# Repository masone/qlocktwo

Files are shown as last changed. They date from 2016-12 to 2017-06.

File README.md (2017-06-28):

# qlocktwo

Arduino based DIY qlocktwo clone. French. Original: http://qlocktwo.com

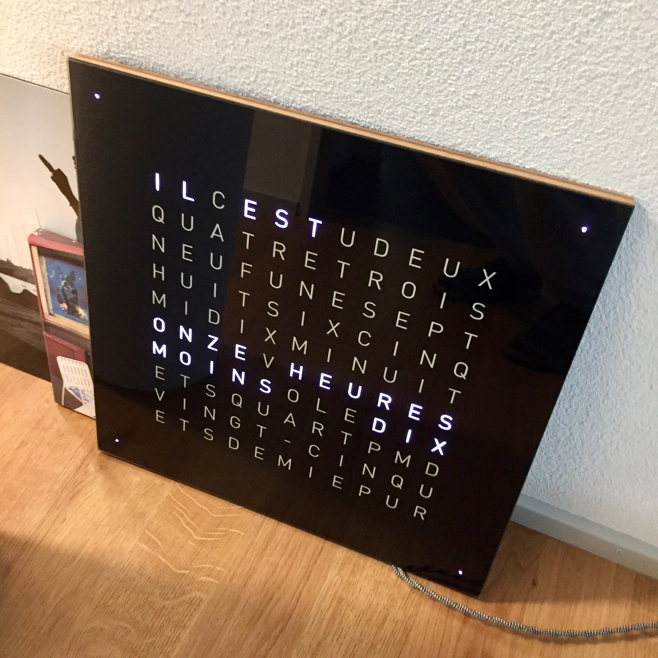
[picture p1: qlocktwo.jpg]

         
## Inspiration

* https://www.flickr.com/photos/ruudburger/sets/72157622708125775/           
* https://www.flickr.com/photos/eokgnah/sets/72157626846176659
* http://jamesbastow.com/wiki/Antelope
* http://imgur.com/a/iMXmj?gallery
* http://www.highonsolder.com/blog/2011/1/8/arduino-word-clock.html

## Resources
                  
* RTC wiring example: http://www.hobbyist.co.nz/?q=real_time_clock
* RTC code examples: https://learn.adafruit.com/ds1307-real-time-clock-breakout-board-kit/understanding-the-code
* 8806 led strip overview: http://www.adafruit.com/product/306
* 8806 led strip code examples: https://learn.adafruit.com/adafruit-neopixel-uberguide/arduino-library
* Wire library (i2c): http://playground.arduino.cc/Main/WireLibraryDetailedReference
* Font: Din regular, 59$: http://www.fonts.com/font/fontfont/ff-din/regular
* Handling vinyl foils, weeding, transfer tape, etc: https://www.youtube.com/watch?v=9TwPV1Wdoog
* Oracal 631-070: http://www.orafol.com/gp/americas/en/products/search-result-gpam-product-details/items/oracal-631-exhibition-cal
* Oratape HT55: http://www.orafol.com/gp/americas/en/products/sign-display-tapes-9755-product-details/items/oratape-ht55-decorative-film-application-tape

## Material

* Vinyl sticker: 456x456mm, black matt, Reverse Cut from https://www.vinylletteringonline.co.uk
* Magnets: MM-S15-3N, 15x3mm, NiCuNi, 2.9kg from https://www.supermagnete.ch
* Wood and glass: 456x456mm from http://jumbo.ch

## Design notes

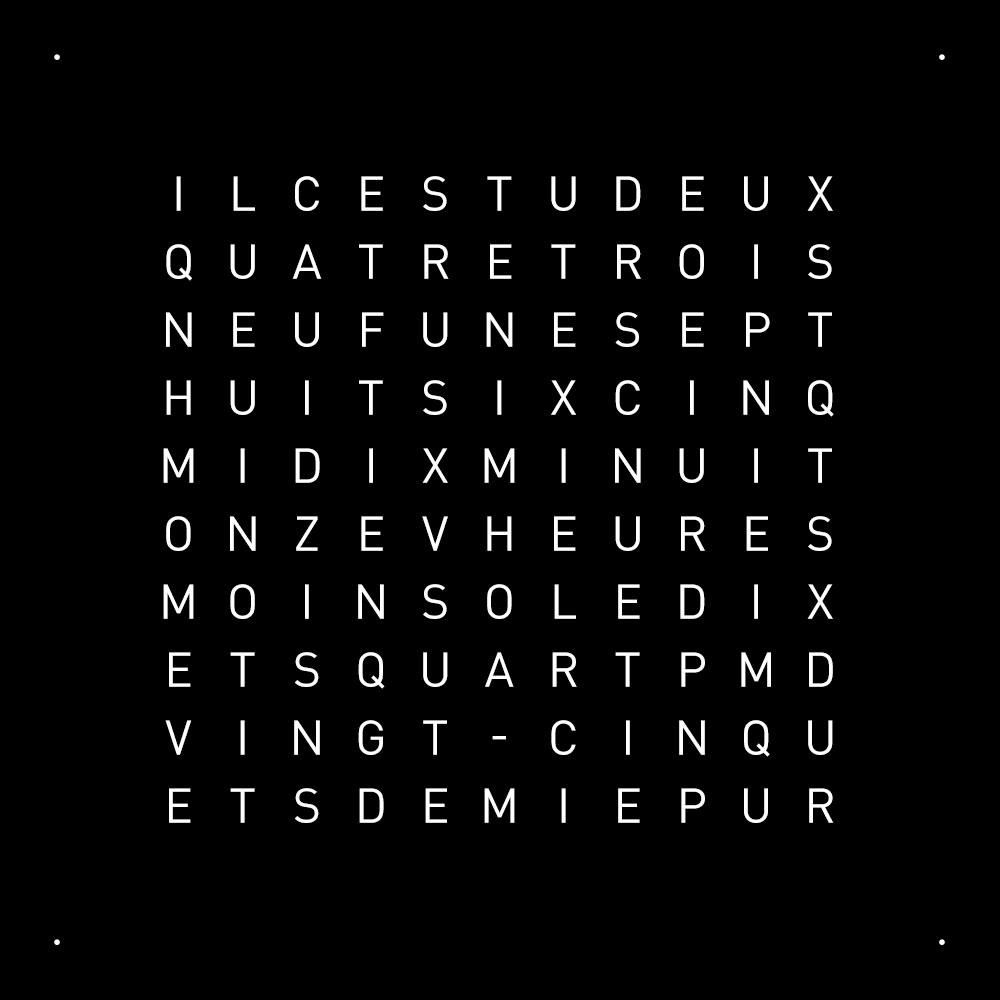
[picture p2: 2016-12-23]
front.jpg

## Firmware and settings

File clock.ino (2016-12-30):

#include "Wire.h"
#include "math.h"
#include "RTClib.h"
#include "LPD8806.h"
#include "SPI.h" // lpd8806 dependency

// RTC SCL (yellow): Analog in 5
// RTC SDA (blue): Analog in 4

int ledDataPin  = 6; // LED DI (blue), digital
int ledClockPin = 7; // LED CI (yellow), digital
int lightPin = 1; // Photoresistor, Analog
int buttonPin = 4; // Push button, digital

DateTime now;
int intensity = 100;
int min_intensity = 10;
int max_intensity = intensity;
int nLEDs = 118;
int reset = 1;

RTC_DS1307 rtc;
LPD8806 leds = LPD8806(nLEDs, ledDataPin, ledClockPin);

void (*words_hour[24])();
void (*words_minute[12])();

void setup() {
  Serial.begin(57600);
  pinMode(buttonPin, INPUT);

  init_leds();
  init_rtc();
  check_reset();
  setup_words();
  test_all();
}

void loop() {
  now = rtc.now();  
  adapt_intensity();

  reset_leds();
  if(digitalRead(buttonPin) == HIGH){
    test_words();
  }else{
    display_time();
  }

  delay(1000);
}

void print_time(int hour, int minute, int second){
  Serial.print(hour, DEC);
  Serial.print(':');
  Serial.print(minute, DEC);
  Serial.print(':');
  Serial.print(second, DEC);
  Serial.println();
}

void init_leds(){
  leds.begin();
  leds.show();
}

void init_rtc(){
#ifdef AVR
  Wire.begin();
#else
  Wire1.begin(); // Shield I2C pins connect to alt I2C bus on Arduino Due
#endif
  rtc.begin();

  if (!rtc.isrunning()) {
    // Time is not set. Upload sketch, hold button to set the time.
    error();
    Serial.println("RTC is NOT running!");
  }
}

void error(){
  leds.setPixelColor(0, 255, 0, 0);
  leds.show();
}

void check_reset(){
  if(reset == 1 && digitalRead(buttonPin) == HIGH){
    Serial.println(F("Resetting time to..."));
    Serial.println(__TIME__);
    Serial.println(__DATE__);
    rtc.adjust(DateTime(__DATE__, __TIME__)); // Reset time to the compilation time
  }

  reset = 0;
}

void adapt_intensity(){
  intensity = map(analogRead(lightPin), 0, 1023, min_intensity, max_intensity);
}

void display_time(){
  int hour = now.hour();
  int minute = now.minute();
  int second = now.second();

  if(minute >= 35){
    hour = hour+1; // adjusts the hour. at 7:35, the french actually say "8 moins 25"
  }

  int rest_minute = (minute % 5);
  int rounded_minute = minute-rest_minute;

  _il_est();

  if(hour == 1 || hour == 13){
    _heure();
  } else if (hour % 12 != 0){
    _heures(); // show the word "hours" unless it's 00:xx or 12:xx
  }

  show_hour(hour);
  show_minute(rounded_minute / 5);
  show_minute_edges(rest_minute);

  leds.show();
  print_time(hour, minute, second);
}

void setup_words(){
  words_hour[0] = _minuit;
  words_hour[1] = _une;
  words_hour[2] = _deux;
  words_hour[3] = _trois;
  words_hour[4] = _quatre;
  words_hour[5] = _cinq;
  words_hour[6] = _six;
  words_hour[7] = _sept;
  words_hour[8] = _huit;
  words_hour[9] = _neuf;
  words_hour[10] = _dix;
  words_hour[11] = _onze;
  words_hour[12] = _midi;
  words_hour[13] = _une;
  words_hour[14] = _deux;
  words_hour[15] = _trois;
  words_hour[16] = _quatre;
  words_hour[17] = _cinq;
  words_hour[18] = _six;
  words_hour[19] = _sept;
  words_hour[20] = _huit;
  words_hour[21] = _neuf;
  words_hour[22] = _dix;
  words_hour[23] = _onze;

  words_minute[0] = _nul;
  words_minute[1] = _cinq2;
  words_minute[2] = _dix2;
  words_minute[3] = _et_quart;
  words_minute[4] = _vingt;
  words_minute[5] = _vingt_cinq;
  words_minute[6] = _et_demie;
  words_minute[7] = _moins_vingt_cinq;
  words_minute[8] = _moins_vingt;
  words_minute[9] = _moins_le_quart;
  words_minute[10] = _moins_dix;
  words_minute[11] = _moins_cinq;
}

void test_all(){
  for(int i=0; i < nLEDs; i++) {
    light_on(i+1);
    leds.show();
    delay(50);
  }
  delay(3000);
  reset_leds();
}


void test_words(){
  test_hours();
  test_minutes();
  test_edges();
}

void test_hours(){
  for(int i=0; i < 24; i++){
    show_hour(i);
    leds.show();
    delay(1500);
    reset_leds();
  }
}

void test_minutes(){
  for(int i=1; i < 12; i++){
    show_minute(i);
    leds.show();
    delay(1500);
    reset_leds();
  }
}

void test_edges(){
  for(int i=1; i <= 4; i++) {
    show_minute_edges(i);
    leds.show();
    delay(1500);
    reset_leds();
  }  
}

void reset_leds(){
  for(int i=0; i < leds.numPixels(); i++) {
    light_off(i+1);
  }
}

void light_on(int i){
  leds.setPixelColor(i-1, color());
}

void light_off(int i){
  leds.setPixelColor(i-1, 0);
}

uint32_t color(){
  int month = now.month();
  int day = now.day();
  int second = now.second();

  if((day == 8 && month == 4) || (day == 6 && month == 10)  || (day == 14 && month == 9)){
    return Wheel(map(second, 0, 60, 0, 384));
  } else {
    return leds.Color(intensity*0.8, intensity*0.9, intensity);
  }
}

void show_hour(int i){
  (*words_hour[i])();
}

void show_minute(int i){
  (*words_minute[i])();
}

void show_minute_edges(int i){
  switch (i) {
  case 1:
    _m();
    break;
  case 2:
    _mm();
    break;
  case 3:
    _mmm();
    break;
  case 4:
    _mmmm();
    break;
  }
}

/* times */
void _m(){
  light_on(115);
}
void _mm(){
  _m();
  light_on(118);
}
void _mmm(){
  _mm();
  light_on(111);
}
void _mmmm(){
  _mmm();
  light_on(114);
}

void _heure(){
  light_on(55);
  light_on(66);
  light_on(75);
  light_on(86);
  light_on(95);
}
void _heures(){
  _heure();
  light_on(106);
}
void _il_est(){
  light_on(1);
  light_on(20);

  light_on(40);
  light_on(41);
  light_on(60);
}
void _une(){
  light_on(43);
  light_on(58);
  light_on(63);
}
void _deux(){
  light_on(80);
  light_on(81);
  light_on(100);
  light_on(101);
}
void _trois(){
  light_on(62);
  light_on(79);
  light_on(82);
  light_on(99);
  light_on(102);
}
void _quatre(){
  light_on(2);
  light_on(19);
  light_on(22);
  light_on(39);
  light_on(42);
  light_on(59);
}
void _cinq(){
  light_on(77);
  light_on(84);
  light_on(97);
  light_on(104);
}
void _six(){
  light_on(44);
  light_on(57);
  light_on(64);
}
void _sept(){
  light_on(78);
  light_on(83);
  light_on(98);
  light_on(103);
}
void _huit(){
  light_on(4);
  light_on(17);
  light_on(24);
  light_on(37);
}
void _neuf(){
  light_on(3);
  light_on(18);
  light_on(23);
  light_on(38);
}
void _dix(){
  light_on(25);
  light_on(36);
  light_on(45);
}
void _onze(){
  light_on(6);
  light_on(15);
  light_on(26);
  light_on(35);
}
void _midi(){
  light_on(5);
  light_on(16);
  light_on(25);
  light_on(36);
}
void _minuit(){
  light_on(56);
  light_on(65);
  light_on(76);
  light_on(85);
  light_on(96);
  light_on(105);
}

void _nul(){
}
void _cinq2(){
  light_on(69);
  light_on(72);
  light_on(89);
  light_on(92);
}
void _dix2(){
  light_on(87);
  light_on(94);
  light_on(107);
}
void _et(){
  light_on(8);
  light_on(13);
}
void _le(){
  light_on(67);
  light_on(74);
}
void _quart(){
  light_on(33);
  light_on(48);
  light_on(53);
  light_on(68);
  light_on(73);
}
void _et_quart(){
  _et();
  _quart();
}
void _vingt(){
  light_on(9);
  light_on(12);
  light_on(29);
  light_on(32);
  light_on(49);
}
void _vingt_cinq(){
  _vingt();
  light_on(52);
  _cinq2();
}
void _et_demie(){
  light_on(10);
  light_on(11);

  light_on(31);
  light_on(50);
  light_on(51);
  light_on(70);
  light_on(71);
}

void _moins(){
  light_on(7);
  light_on(14);
  light_on(27);
  light_on(34);
  light_on(47);
}
void _moins_vingt_cinq(){
  _moins();
  _vingt_cinq();
}
void _moins_vingt(){
  _moins();
  _vingt();
}
void _moins_le_quart(){
  _moins();
  _le();
  _quart();
}
void _moins_dix(){
  _moins();
  _dix2();
}
void _moins_cinq(){
  _moins();
  _cinq2();
}


// Input a value 0 to 384 to get a color value.
// The colours are a transition r - g -b - back to r
uint32_t Wheel(int WheelPos)
{
  byte r, g, b;
  switch(WheelPos / 128)
  {
    case 0:
      r = 127 - WheelPos % 128;   //Red down
      g = WheelPos % 128;      // Green up
      b = 0;                  //blue off
      break;
    case 1:
      g = 127 - WheelPos % 128;  //green down
      b = WheelPos % 128;      //blue up
      r = 0;                  //red off
      break;
    case 2:
      b = 127 - WheelPos % 128;  //blue down
      r = WheelPos % 128;      //red up
      g = 0;                  //green off
      break;
  }
  return(leds.Color(r,g,b));
}

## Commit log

2015-04-10 fritzing pcb
    [clock.fzz]
2015-04-28 fixes bug with dix/dix2
    [clock.ino]
2015-04-28 adds electronical parts to fritzing
    [clock.fzz]
2016-12-23 intensity tweaks, test all leds
2016-12-23 fix minutes
    prevent accessing random memory when hitting unpopulated array indexes
    [clock.ino]
2016-12-23 reset leds on every loop
    [clock.ino]
